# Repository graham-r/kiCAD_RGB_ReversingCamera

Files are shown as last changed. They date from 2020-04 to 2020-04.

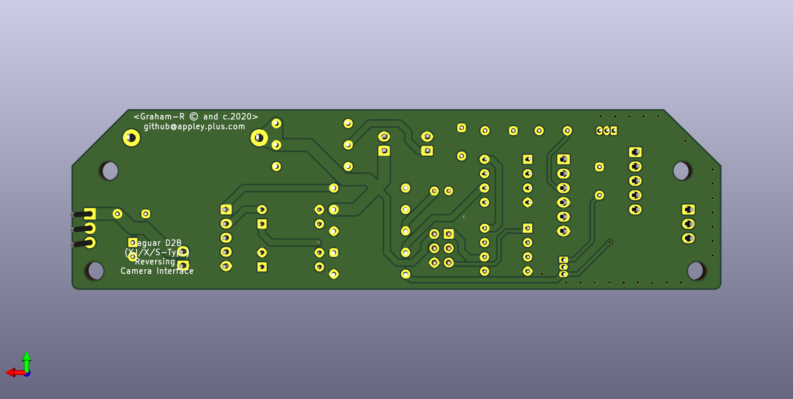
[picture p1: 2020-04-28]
RGB_ReversingCam_FSAV433_ATTINY85_v3.2/images/RGB_ReversingCam_FSAV433_ATTINY85_v3.2_SoldertSide.png

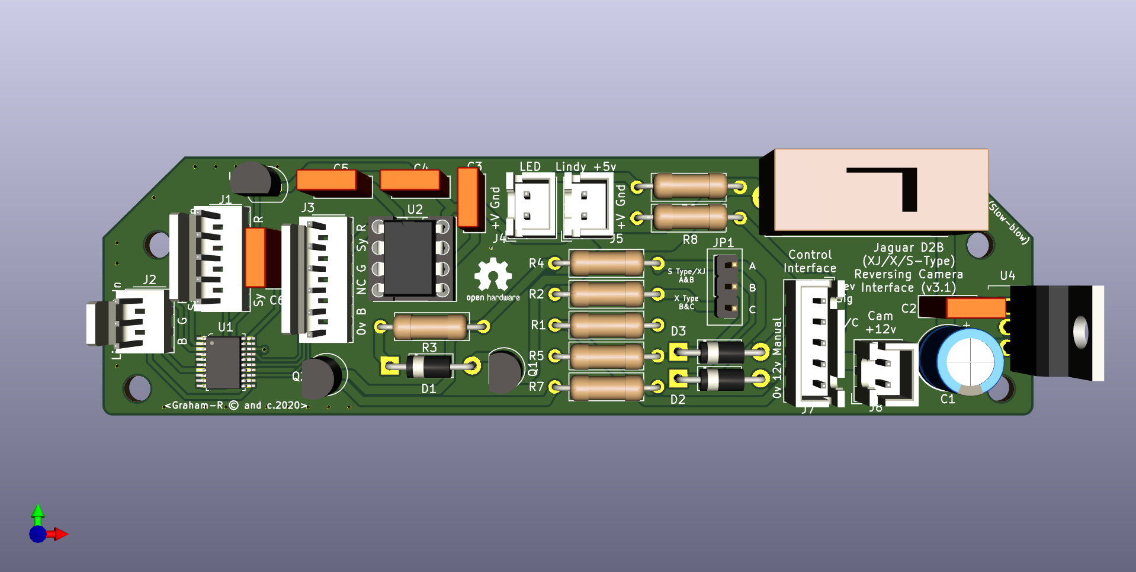
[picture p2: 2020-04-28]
RGB_ReversingCam_FSAV433_v3.1/images/RGB_ReversingCam_FSAV433_v3.1_ComponentSide.png

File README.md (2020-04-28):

# A&R A60 Amplifier KICAD projects

Version 8.01 differences

Compact style PCB
Power & speaker fuses removed
Common input socket (Left & Right)
+/-36v Power rails decoupled between power amp stage & input stage

NOTE: These are experiments in using KICAD - they are untested as they have not been built
(unless stated otherwise in the README file in a specific directory).

The projects contained in this repository are all based on the A&R A60 or A60AP integrated
amplifiers, currently limited to issue 8 (25502 onwards schematics).

The copyright of the circuits remain with the original owners, the Schematic and hardware
copyright are open source.

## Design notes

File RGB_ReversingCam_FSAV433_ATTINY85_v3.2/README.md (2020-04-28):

# Reversing camera interface for cars with an RGB  interface.

The projects in this repository have been tested (in Vero-board) prototype form for many
years on D2B equipped Jaguar X Type (X400) & S Type (X200) - will also work on the XJ (X350)

This module uses an FSAV433 video switch to switch between RGB & Sync (the default channel)
and an RGB & 'Sync-on-Green' camera input. The latter must be converted from cmposite to
RGB using a suitable video converter, in this case a 'Lindy' module was used.

This version uses an ATtiny85 Arduino style IC to control the reversing camera switching.

NOTE: These are experiments in using KICAD - they are untested as they have not been built
(unless stated otherwise in the README file in a specific directory).

The projects contained in this repository are all based on the A&R A60 or A60AP integrated
amplifiers, currently limited to issue 8 (25502 onwards schematics).

The copyright of the circuits remain with the original owners, the Schematic and hardware
copyright are open source.

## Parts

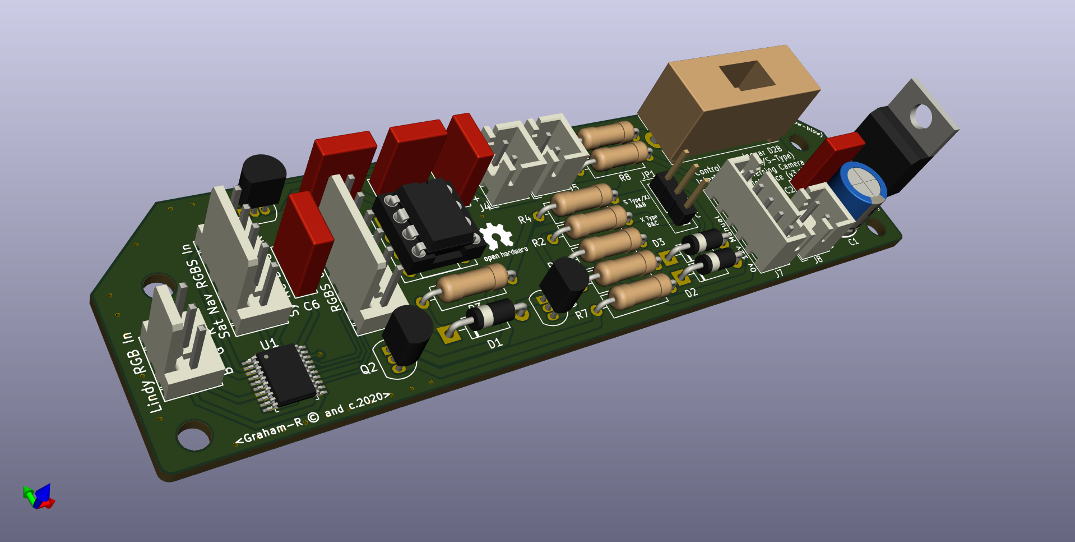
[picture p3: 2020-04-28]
RGB_ReversingCam_FSAV433_v3.1/images/RGB_ReversingCam_FSAV433_v3.1_ComponentSide_3.png

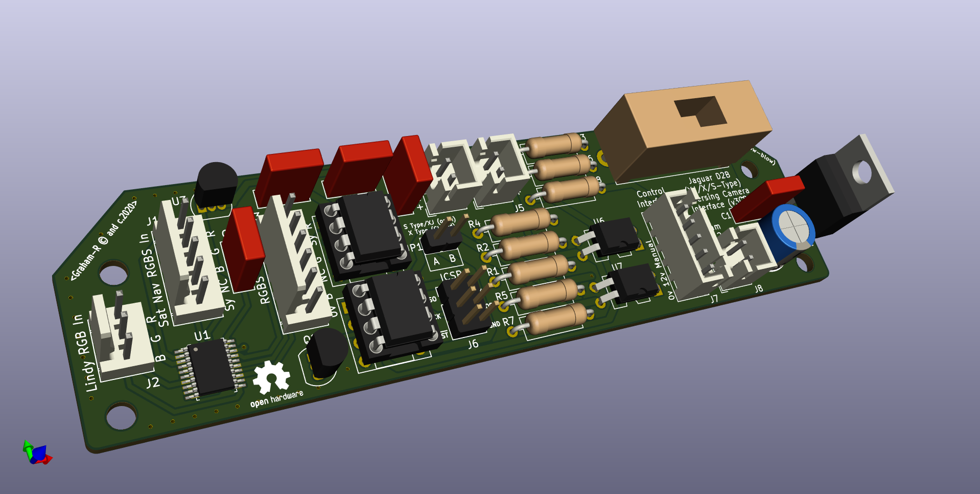
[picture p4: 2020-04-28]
RGB_ReversingCam_FSAV433_ATTINY85_v3.2/images/RGB_ReversingCam_FSAV433_ATTINY85_v3.2_ComponentSide_3.png

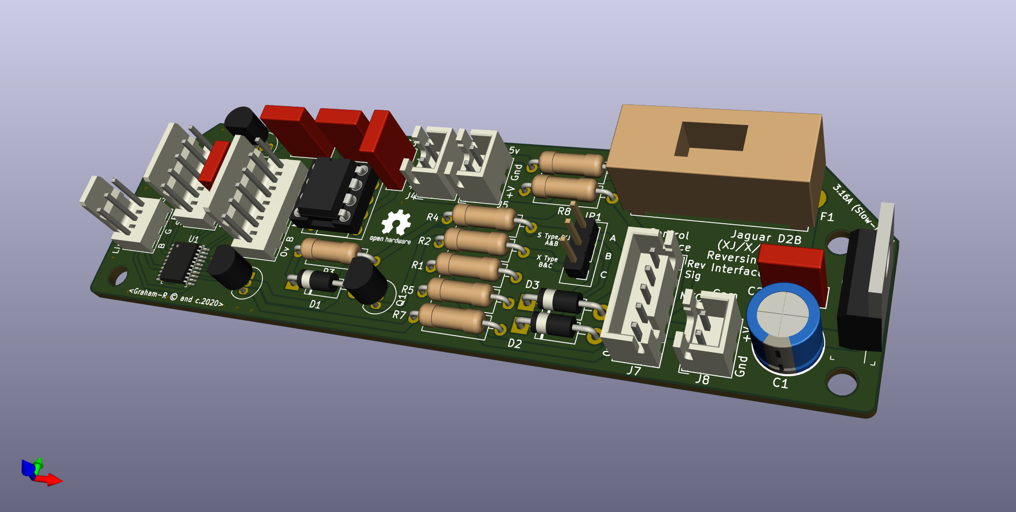
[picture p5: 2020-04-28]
RGB_ReversingCam_FSAV433_v3.1/images/RGB_ReversingCam_FSAV433_v3.1_ComponentSide_2.png

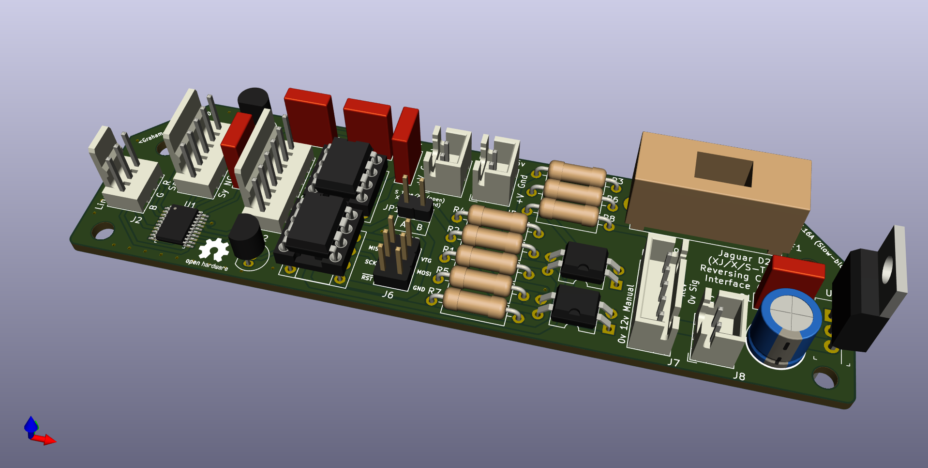
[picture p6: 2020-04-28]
RGB_ReversingCam_FSAV433_ATTINY85_v3.2/images/RGB_ReversingCam_FSAV433_ATTINY85_v3.2_ComponentSide_2.png

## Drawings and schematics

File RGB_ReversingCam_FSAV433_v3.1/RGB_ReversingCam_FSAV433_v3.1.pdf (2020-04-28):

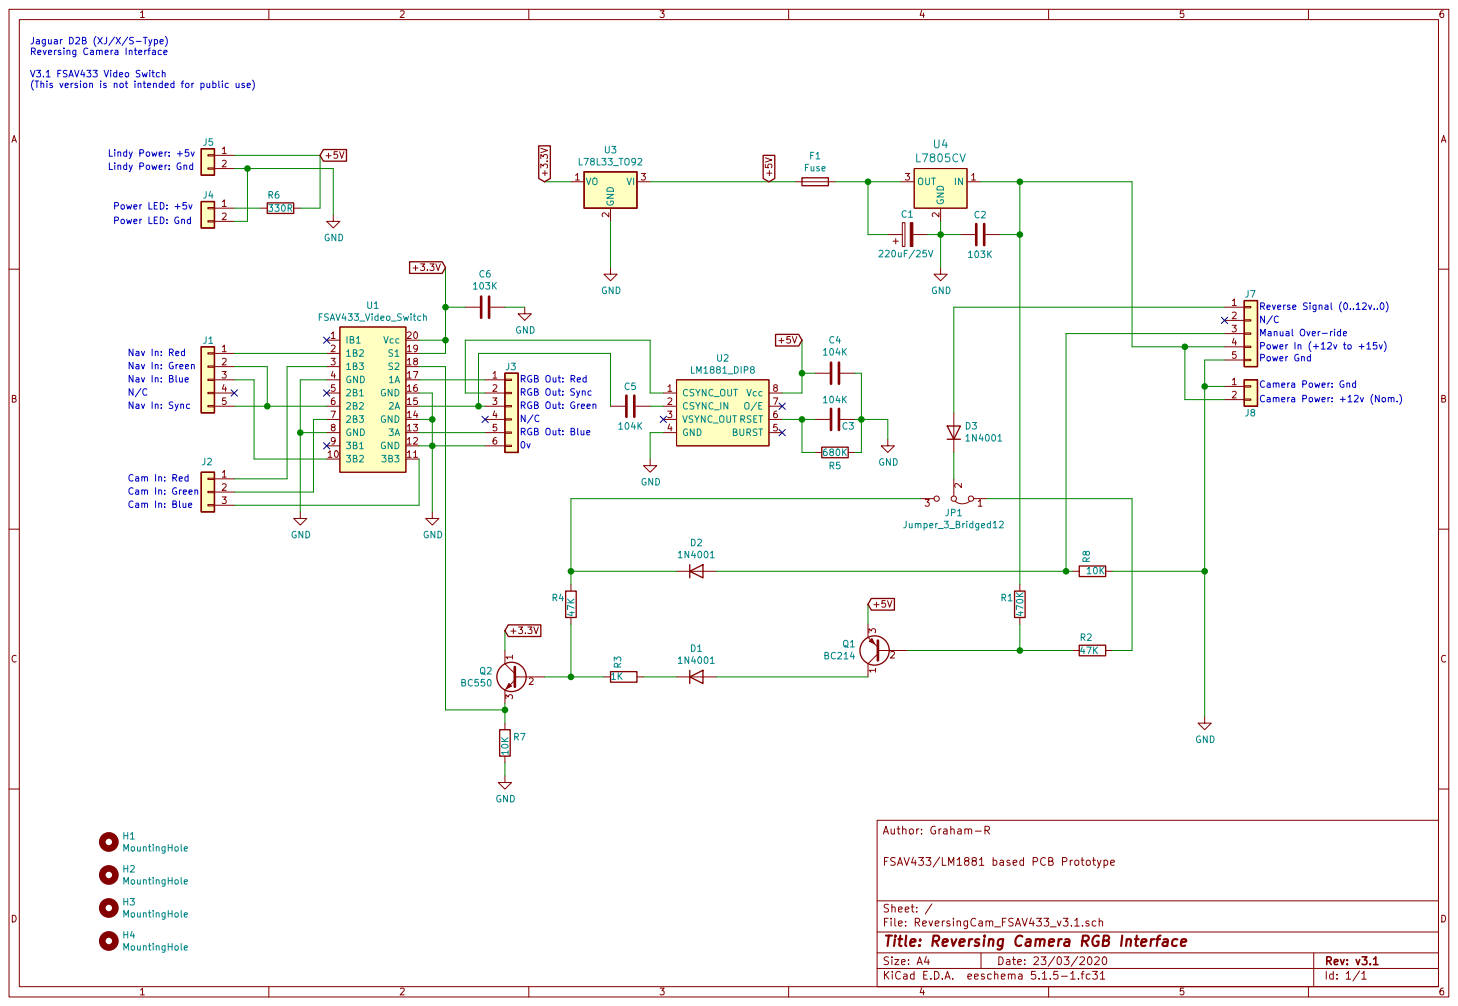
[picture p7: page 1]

Lindy Power: Gnd Power LED: Gnd V3.1 FSAV433 Video Switch
(This version is not intended for public use)

0v Nav In: Red Nav In: Green Nav In: Blue N/C

File: ReversingCam_FSAV433_v3.1.sch Sheet: / FSAV433/LM1881 based PCB Prototype Author: Graham-R

Id: 1/1 Title: Reversing Camera RGB Interface

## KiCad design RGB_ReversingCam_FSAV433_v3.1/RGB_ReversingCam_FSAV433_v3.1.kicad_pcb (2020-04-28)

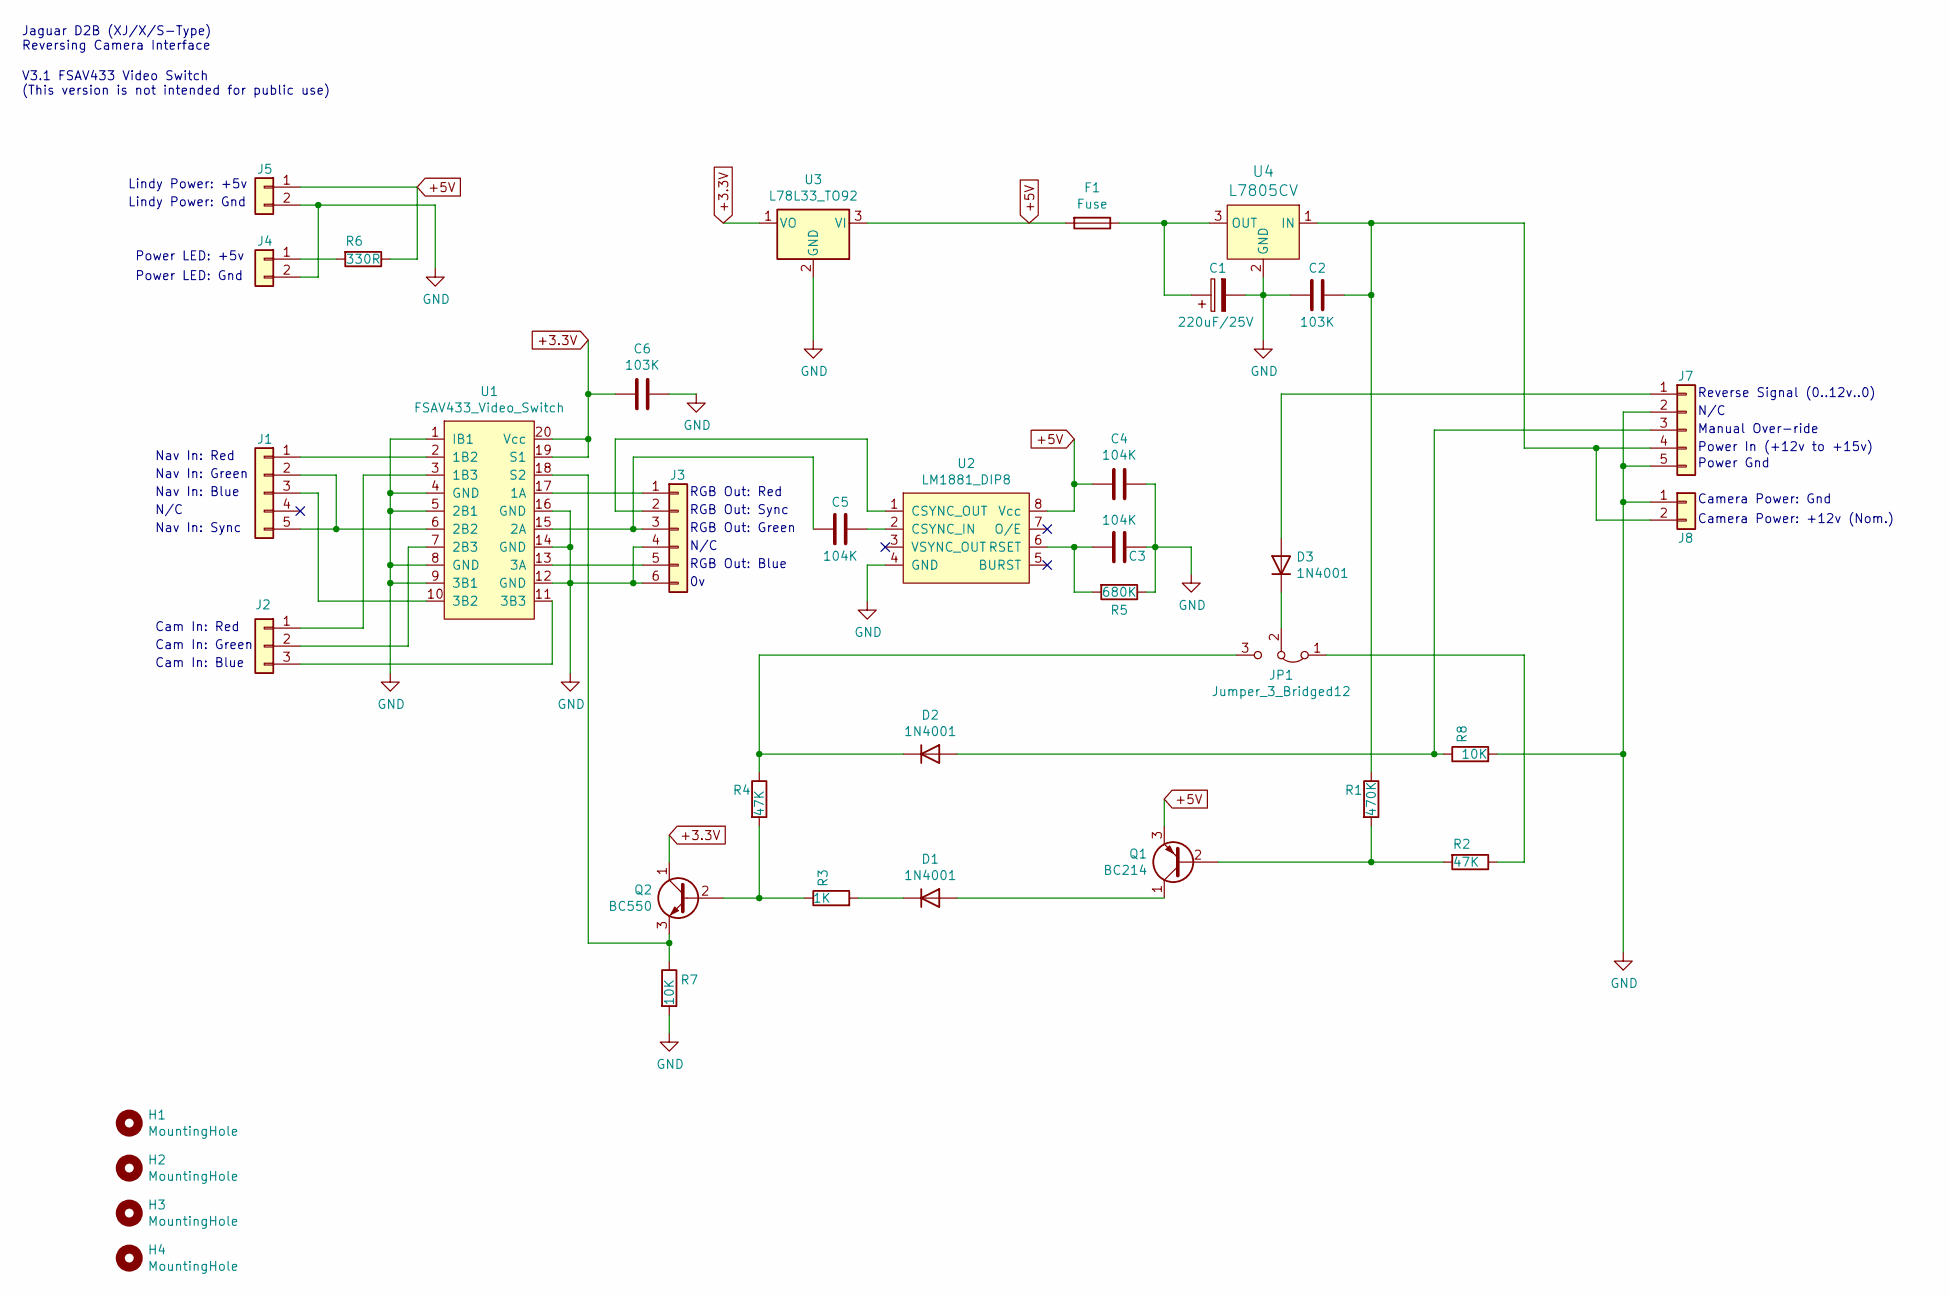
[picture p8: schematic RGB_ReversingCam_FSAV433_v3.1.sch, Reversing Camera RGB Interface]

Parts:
C1: 220uF/25V; CP_Radial_D8.0mm_P2.50mm
C2, C6: 103K; C_Rect_L7.0mm_W2.5mm_P5.00mm
C3, C4, C5: 104K; C_Rect_L7.0mm_W2.5mm_P5.00mm
D1, D2, D3: 1N4001; D_DO-41_SOD81_P10.16mm_Horizontal
F1: Fuse; Fuseholder_Cylinder-5x20mm_Stelvio-Kontek_PTF78_Horizontal_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
H1, H2, H3: MountingHole; MountingHole_3.2mm_M3_ISO7380
H4: MountingHole; MountingHole_3.2mm_M3_ISO7380_no_courtyard
J1: Conn_01x05; Molex_KK-254_AE-6410-05A_1x05_P2.54mm_Vertical
J2: Conn_01x03; Molex_KK-254_AE-6410-03A_1x03_P2.54mm_Vertical
J3: Conn_01x06; Molex_KK-254_AE-6410-06A_1x06_P2.54mm_Vertical
J4, J5: Conn_01x03; JST_XH_B2B-XH-A_1x02_P2.50mm_Vertical
J7: Conn_01x05; JST_XH_B5B-XH-A_1x05_P2.50mm_Vertical
J8: Conn_01x02; JST_XH_B2B-XH-A_1x02_P2.50mm_Vertical
JP1: Jumper_3_Bridged12; PinHeader_1x03_P2.54mm_Vertical
Q1: BC214; TO-92_Inline
Q2: BC550; TO-92_Inline
R1: 470K; R_Axial_DIN0309_L9.0mm_D3.2mm_P12.70mm_Horizontal
R2, R4: 47K; R_Axial_DIN0309_L9.0mm_D3.2mm_P12.70mm_Horizontal
R3: 1K; R_Axial_DIN0309_L9.0mm_D3.2mm_P12.70mm_Horizontal
R5: 680K; R_Axial_DIN0309_L9.0mm_D3.2mm_P12.70mm_Horizontal
R6: 330R; R_Axial_DIN0309_L9.0mm_D3.2mm_P12.70mm_Horizontal
R7, R8: 10K; R_Axial_DIN0309_L9.0mm_D3.2mm_P12.70mm_Horizontal
U1: FSAV433_Video_Switch; TSSOP-20_W4.4mm
U2: LM1881_DIP8; DIP-8_W7.62mm_Socket
U3: L78L33_TO92; TO-92_Inline
U4: L7805CV; TO-220-3; MPN L7805CV; Digi-Key_PN 497-1443-5-ND

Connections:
+3.3V: C6.1, Q2.1 (C), U1.19 (S1), U1.20 (Vcc), U3.1 (VO)
+5V: C4.2, F1.2, J5.1, Q1.3 (E), R6.1, U2.8 (Vcc), U3.3 (VI)
GND: C1.2, C2.1, C3.1, C4.1, C6.2, J3.4, J3.6, J4.2, J5.2, J7.2, J7.5, J8.1, R5.1, R7.2, R8.2, U1.1 (IB1), U1.4 (GND), U1.5 (2B1), U1.8 (GND), U1.9 (3B1), U1.12 (GND), U1.14 (GND), U1.16 (GND), U2.4 (GND), U3.2 (GND), U4.2 (GND)
unnamed: C1.1, F1.1, U4.3 (OUT)
unnamed: C2.2, J7.4, J8.2, R1.1, U4.1 (IN)
unnamed: C3.2, R5.2, U2.6 (RSET)
unnamed: C5.1, U2.2 (CSYNC_IN)
unnamed: C5.2, J3.3, U1.15 (2A)
unnamed: D1.1 (K), R3.2
unnamed: D1.2 (A), Q1.1 (C)
unnamed: D2.1 (K), JP1.3 (B), R4.1
unnamed: D2.2 (A), J7.3, R8.1
unnamed: D3.1 (K), JP1.2 (C)
unnamed: D3.2 (A), J7.1
unnamed: J1.1, U1.2 (1B2)
unnamed: J1.2, J1.5, U1.6 (2B2)
unnamed: J1.3, U1.10 (3B2)
unnamed: J2.1, U1.3 (1B3)
unnamed: J2.2, U1.7 (2B3)
unnamed: J2.3, U1.11 (3B3)
unnamed: J3.1, U1.17 (1A)
unnamed: J3.2, U2.1 (CSYNC_OUT)
unnamed: J3.5, U1.13 (3A)
unnamed: J4.1, R6.2
unnamed: JP1.1 (A), R2.1
unnamed: Q1.2 (B), R1.2, R2.2
unnamed: Q2.2 (B), R3.1, R4.2
unnamed: Q2.3 (E), R7.1, U1.18 (S2)

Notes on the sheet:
RGB Out: Blue
N/C
RGB Out: Green
RGB Out: Sync
RGB Out: Red
Cam In: Blue
Cam In: Green
Cam In: Red
Nav In: Sync
Nav In: Blue
Nav In: Green
Nav In: Red
Reverse Signal (0..12v..0)
Manual Over-ride
Power In (+12v to +15v)
Power Gnd
Camera Power: Gnd
Camera Power: +12v (Nom.)
Jaguar D2B (XJ/X/S-Type) Reversing Camera Interface
V3.1 FSAV433 Video Switch (This version is not intended for public use)
Lindy Power: +5v
Lindy Power: Gnd
Power LED: Gnd
Power LED: +5v

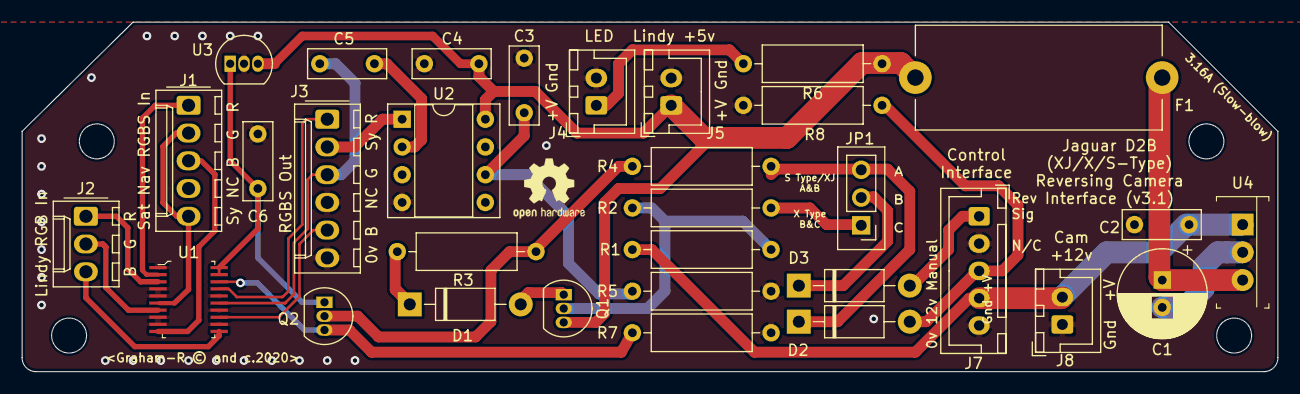
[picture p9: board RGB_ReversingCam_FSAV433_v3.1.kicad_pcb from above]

Board: 2 copper layers, 115.0 x 32.0 mm, 36 parts (0 on the bottom side), 28 nets.
